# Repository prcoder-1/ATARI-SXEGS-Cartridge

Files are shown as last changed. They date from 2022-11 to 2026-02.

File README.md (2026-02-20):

# ATARI SXEGS Cartridge

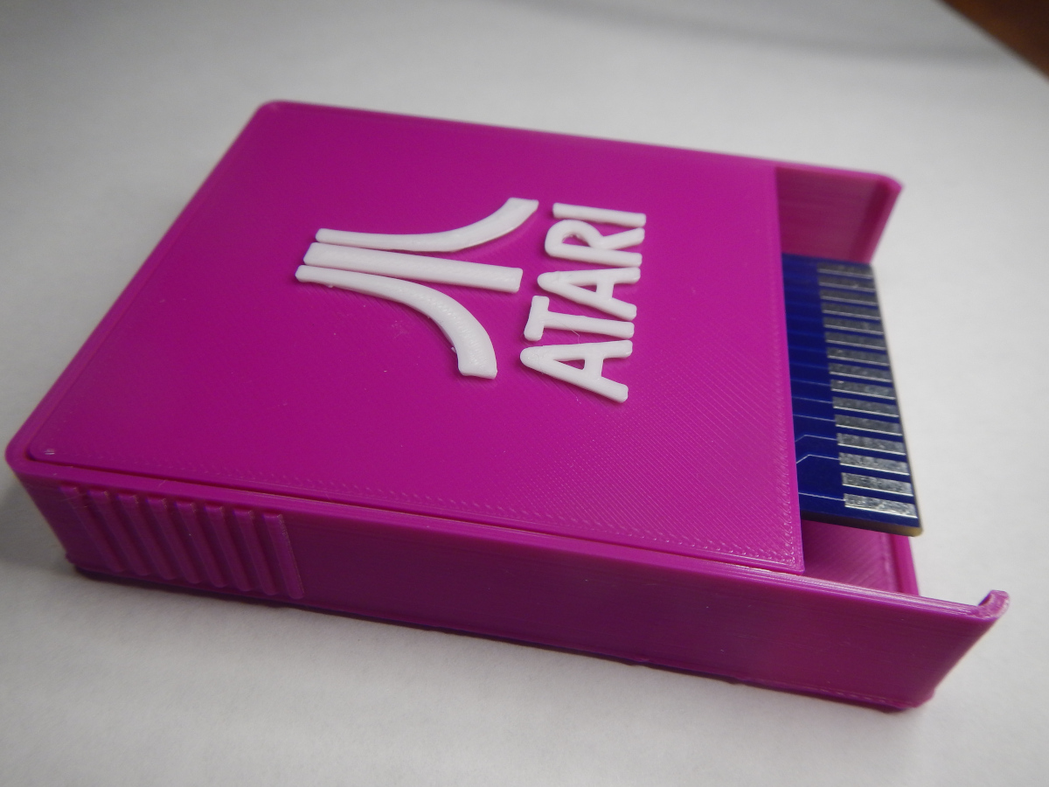
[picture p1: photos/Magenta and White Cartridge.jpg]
Magenta and White Cartridge.jpg


## Cartridge board and Housing for [ATARI 65XE/130XE/800XE/XEGS/1200XL/800XL/600XL/800/400](https://en.wikipedia.org/wiki/Atari_8-bit_family) 8-bit computers based on [SST39SF040](https://www.microchip.com/en-us/product/SST39SF040) CMOS multi-purpose **Flash memory** chip.

- This is a **[S/XEGS type cartridge](https://forums.atariage.com/topic/276194-switchable-xe-game-cartridges-swxegs-andor-sxegs/)** that allows you to store and run dozens of games.
- The project **does not use** programmable logic chips such as [GAL-chips](https://en.wikipedia.org/wiki/Generic_array_logic).
- Only conventional logic chips are used, such as **74LS00N**, **74LS74N** and **74LS374N**.
- In the process of manufacturing a cartridge, microchips of Russian production can be used, such as **ЭКР1533ИР23**, **К555ТМ2**, **К555ЛА3** etc.

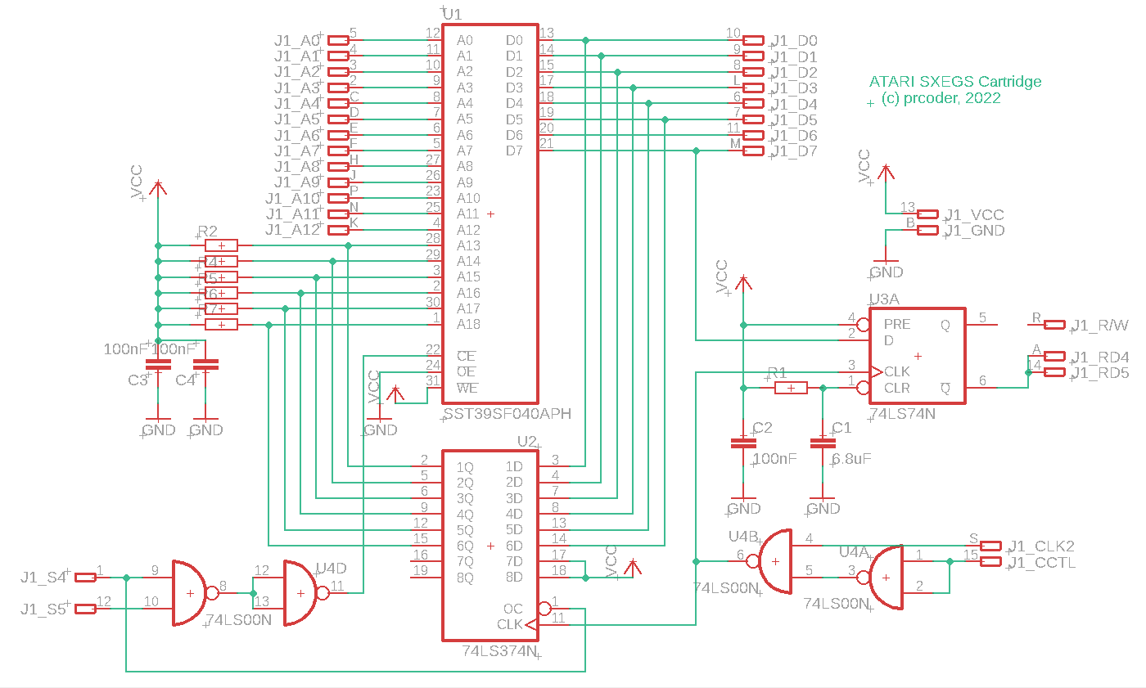
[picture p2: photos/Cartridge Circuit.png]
Cartridge Circuit


The ROM files for the cartridge are created from the XEX files using the ***[CreaXin1](programs/Creaxin1.exe)*** utility,
and then merged using the ***[XEGS Merger](programs/XEGS_merger.exe)*** to combine four files into one, forming a total of **512 kb of ROM** memory.

The cartridge body consists of two 3D-printed parts. The parts connect to each other without the use of screws or glue.

Files:
- ***[XEGS Cartridge_2022-11-28.zip](XEGS%20Cartridge_2022-11-28.zip)*** - archive with Gerber files for PCB manufacturing
- ***[ATARI-Cartridge-v5-Body.stl](ATARI-Cartridge-v5-Body.stl)*** - 3D-model of cartridge housing body
- ***[ATARI-Cartridge-v5-Cover.stl](ATARI-Cartridge-v5-Cover.stl)*** - 3D-model of cartridge housing cover

**[Ready to order project on PCBWay here](https://www.pcbway.com/project/shareproject/ATARI_8bit_SXEGS_Cartridge_Shrinked_Version_2022_11_10_3705ed31.html)**

The following DIP chips are required to build a cartridge:
- SST39SF040 DIP32 (or other JEDEC standard ROM) (1pcs)
- 74LS374N (or ЭКР1533ИР23) DIP20 (1pcs)
- 74LS74N (or К555ТМ2) DIP14 (1pcs)
- 74LS00N (or К555ЛА3) DIP14 (1pcs)

And the following SMD 1206 parts are required to build a cartridge:
- 100 nF capacitors (3 pcs)
- 6.8 uF capacitor (1 pcs)
- 11 kOhm resistors (6 pcs)
- 3.3 kOhm resistor (1 pcs)

Optional: Round Hole IC Socket Connector DIP32 (1pcs) for SST39SF040.

And you need the ability to program the [SST39SF040](https://www.microchip.com/en-us/product/SST39SF040) Flash ROM, of course. Some sort of programmer like TL866II, or something else.

To make a cartridge body, you need the ability to print models on a 3D printer. The model of the cartridge case and its cover is attached.

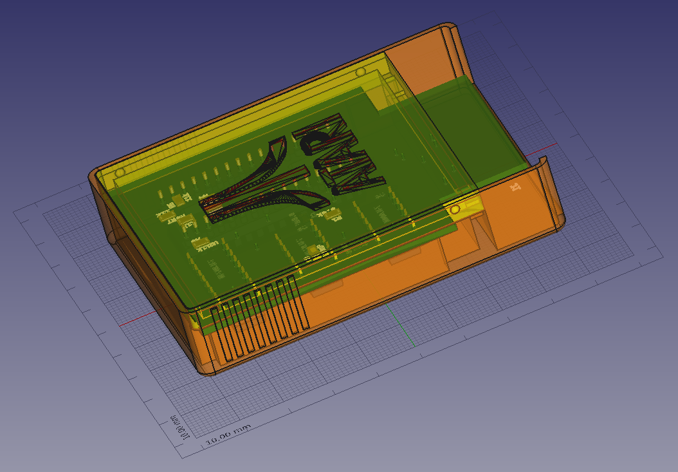
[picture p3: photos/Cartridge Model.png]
Cartridge Model


When assembling the case, no additional fasteners, screws or glue are required. The case cover simply snaps into the body of the case, securing the PCB.

Instructions for creating a binary firmware file to flash in SST39SF040:
1. Download ***[CreaXin1](programs/Creaxin1.exe)*** and ***[XEGS Merger](programs/XEGS_merger.exe)*** utilities.
2. Use '***Creaxin1.exe***' utility to create ***128 kB image file***. Add XEX files to fill 128 kB ROM space and save as 'Xin1 SXEGS cartridge ROM' file.
3. Repeat step 2 ***four times*** to create four 128 kB images with different XEXs.
4. Use '***XEGS merger.exe***' utility to merge four 128 kB images into one ***512 kB image***. Add four 128 kB ROM images, choose 512 kB FLASH SIZE and press 'Create' button.
   Enter name of the new SXEGS ROM file and save it.
5. ***Flash 512 kB ROM image*** into SST39SF040. Erase ROM chip, write image and verify it.
6. Place the written chip in round hole IC socket or solder it into PCB.

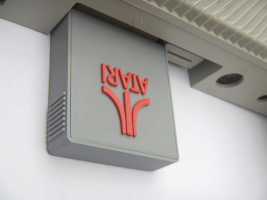
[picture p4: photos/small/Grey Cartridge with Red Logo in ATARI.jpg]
Grey Cartridge with Red Logo in ATARI

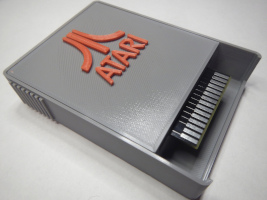
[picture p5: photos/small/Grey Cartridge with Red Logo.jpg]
Grey Cartridge with Red Logo

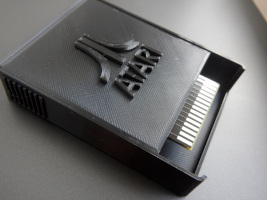
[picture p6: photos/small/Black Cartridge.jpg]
Black Cartridge

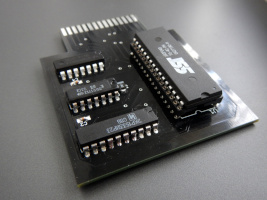
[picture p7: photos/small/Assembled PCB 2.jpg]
Assembled PCB 2

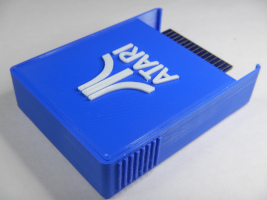
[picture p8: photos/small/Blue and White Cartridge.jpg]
Blue and White Cartridge

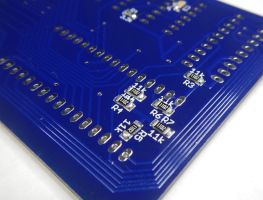
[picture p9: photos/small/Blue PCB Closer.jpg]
Blue PCB Closer

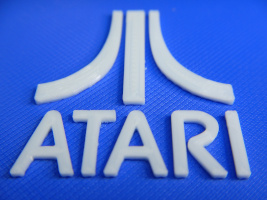
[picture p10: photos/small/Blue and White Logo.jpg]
Blue and Whte Logo

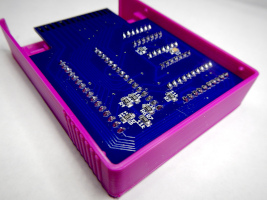
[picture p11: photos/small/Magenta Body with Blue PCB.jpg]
Magenta Body with Blue PCB

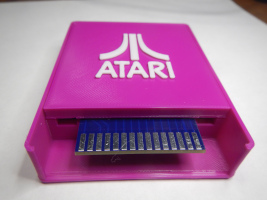
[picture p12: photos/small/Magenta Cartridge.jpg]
Magenta Cartridge

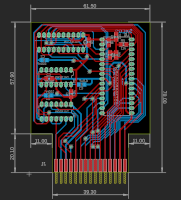
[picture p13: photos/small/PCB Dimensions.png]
PCB Dimensions

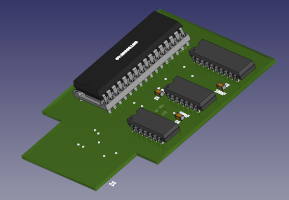
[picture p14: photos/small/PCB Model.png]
PCB Model

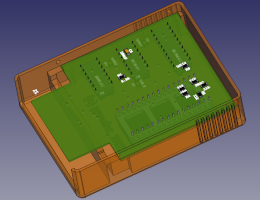
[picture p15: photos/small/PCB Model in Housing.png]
PCB Model in Housing

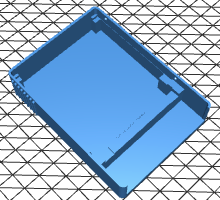
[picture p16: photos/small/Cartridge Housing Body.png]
Cartridge Housing Body

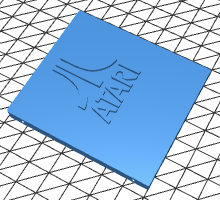
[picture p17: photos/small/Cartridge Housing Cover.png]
Cartridge Housing Cover

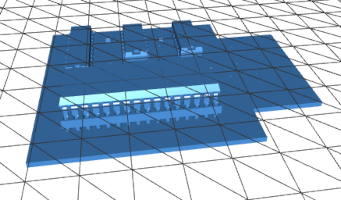
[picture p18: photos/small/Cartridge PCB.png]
Cartridge PCB

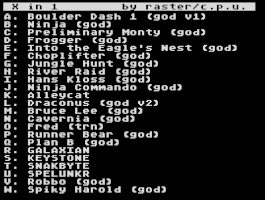
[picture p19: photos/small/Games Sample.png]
Games Sample


*© prcoder, 2022-2023*

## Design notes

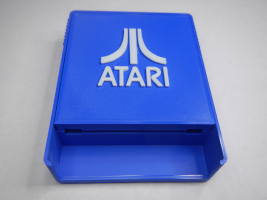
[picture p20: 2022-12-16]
photos/small/Blue Housing.jpg

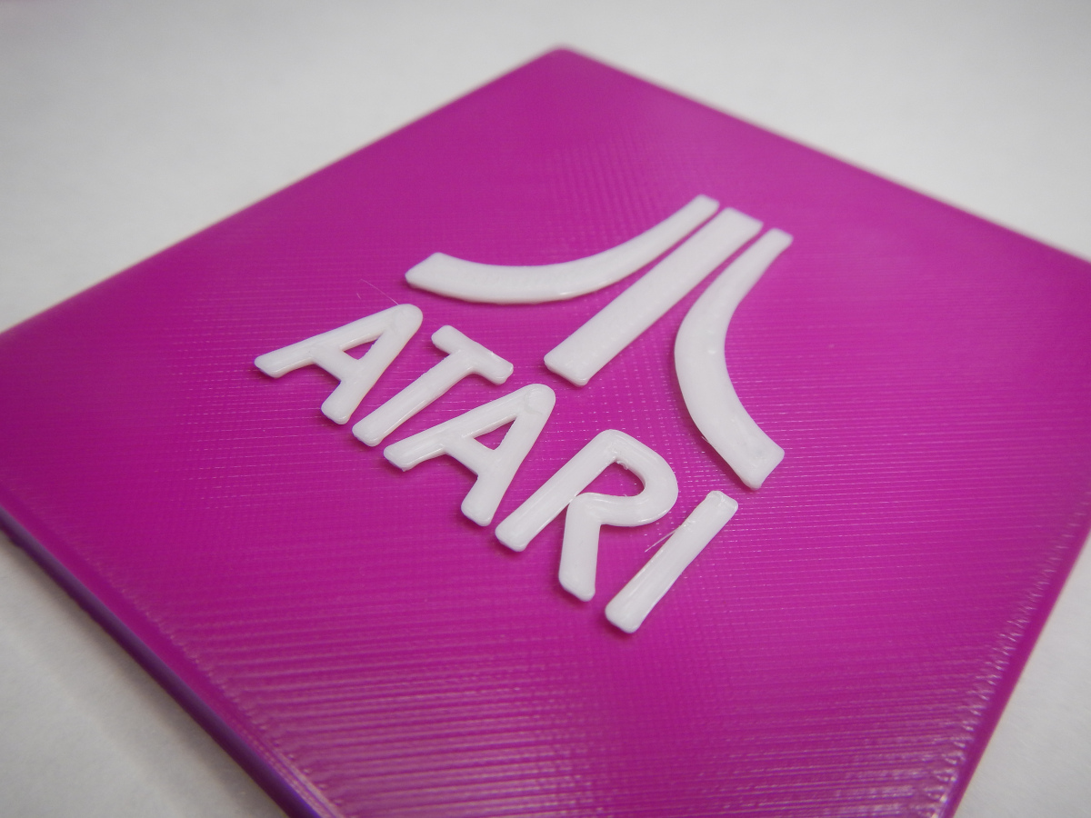
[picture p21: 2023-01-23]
photos/Magenta Cover.jpg

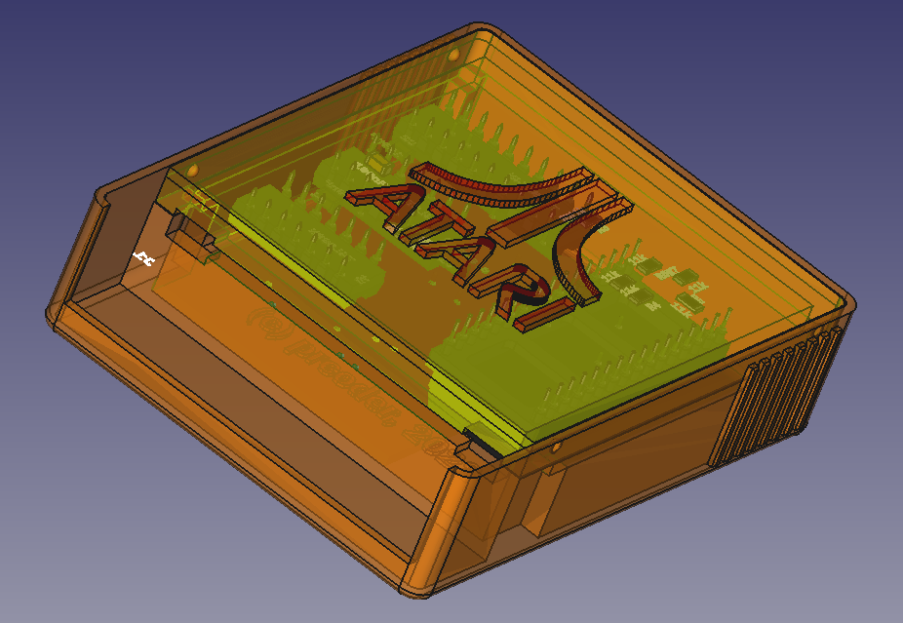
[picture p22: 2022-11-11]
photos/PCB Model with Cover closed.png

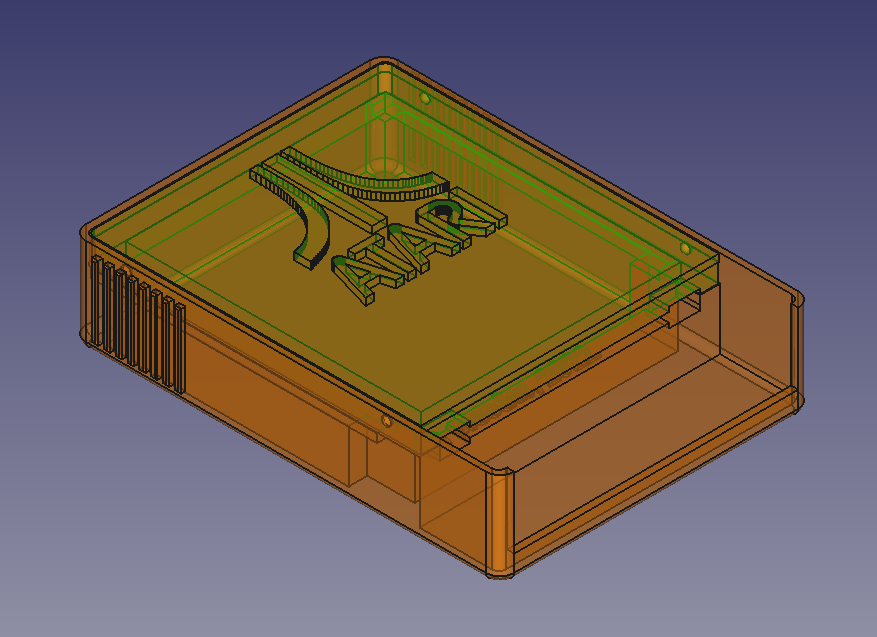
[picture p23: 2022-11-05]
photos/FreeCAD_View.png

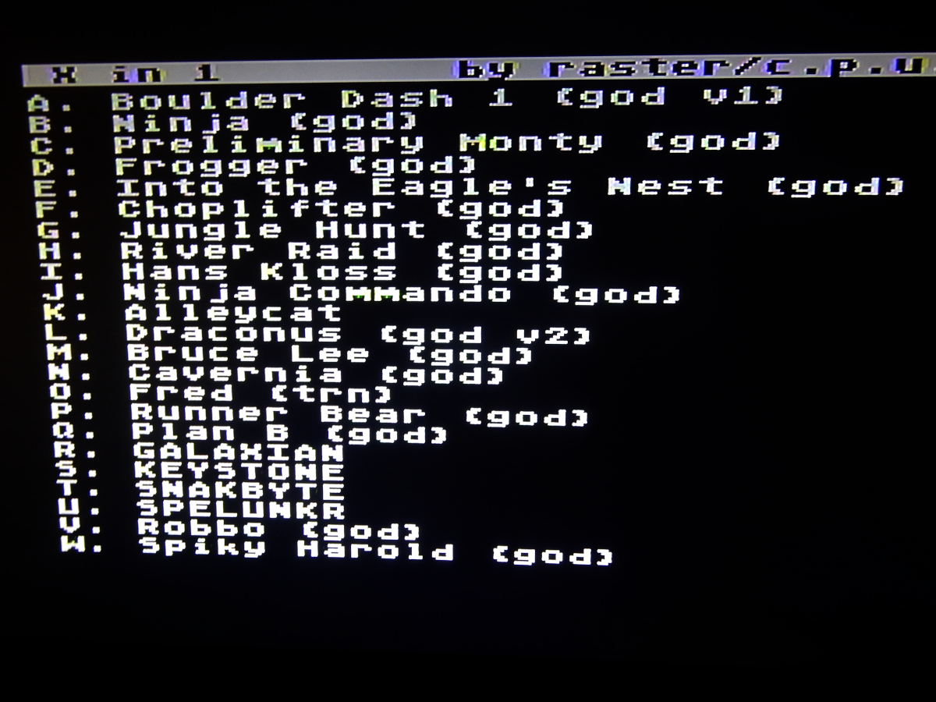
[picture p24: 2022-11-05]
photos/Games List.jpg

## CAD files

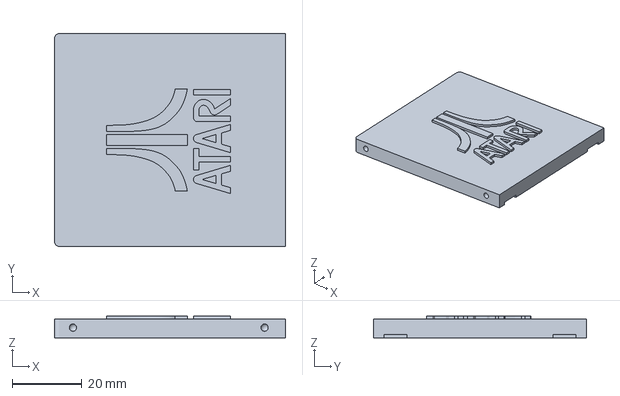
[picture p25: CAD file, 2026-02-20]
ATARI-Cartridge-v5-Cover.3mf
66.3 x 61.2 x 6.26 mm

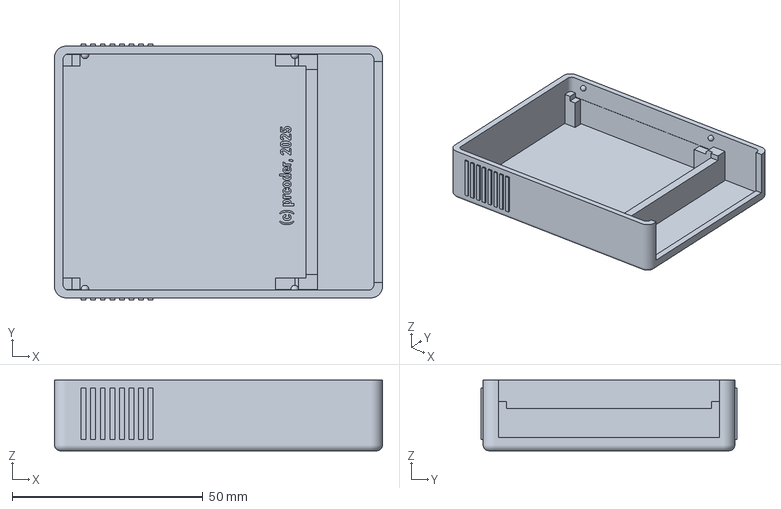
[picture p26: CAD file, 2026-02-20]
ATARI-Cartridge-v5-Body.3mf
86.0 x 67.0 x 18.5 mm

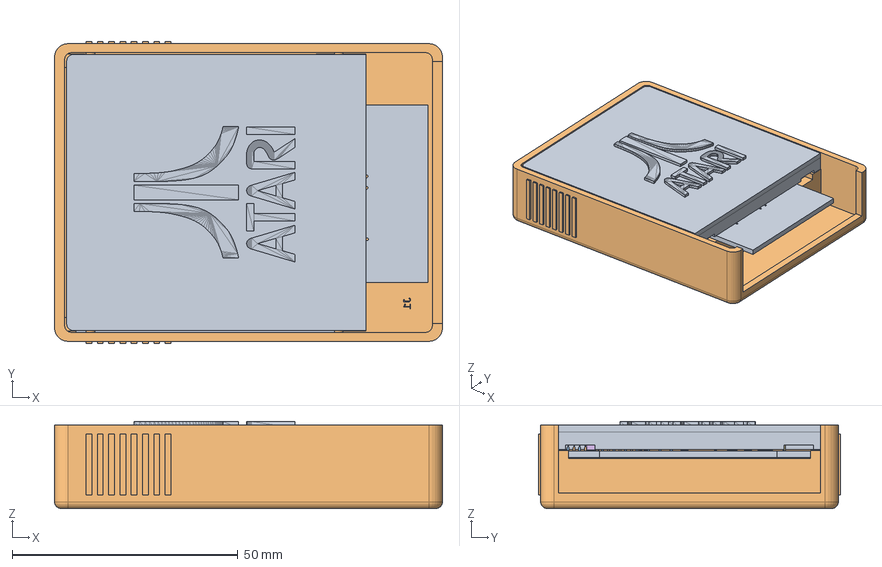
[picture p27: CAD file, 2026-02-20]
ATARI-Cartridge-v5.FCStd
86.0 x 67.0 x 19.3 mm
U3 x 2
U4 x 2
U2 x 2
R2 x 2
R3 x 2
R6 x 2
R7 x 2
R4 x 2
R5 x 2
R1 x 2
C1 x 2
C2 x 2
C4 x 2
C3 x 2
U1 Socket x 2
SST390SF40 x 2
Board x 2
PCBannotation_0000001
PCBannotation_0000
PCBannotation_0000004
PCBannotation_0000005
PCBannotation_0000006
PCBannotation_0000007
PCBannotation_0000009
PCBannotation_0000008
PCBannotation_0000011
PCBannotation_0000010
PCBannotation_0000012
PCBannotation_0000013
PCBannotation_0000014
PCBannotation_0000015
PCBannotation_0000016
PCBannotation_0000017
PCBannotation_0000018
PCBannotation_0000019
PCBannotation_0000020
PCBannotation_0000021
PCBannotation_0000023
PCBannotation_0000022
PCBannotation_0000025
PCBannotation_0000024
PCBannotation_0000026
PCBannotation_0000027
PCBannotation_0000028
PCBannotation_0000029
PCBannotation_0000030
PCBannotation_0000032
PCBannotation_0000034
Крышка с логотипом
Корпус

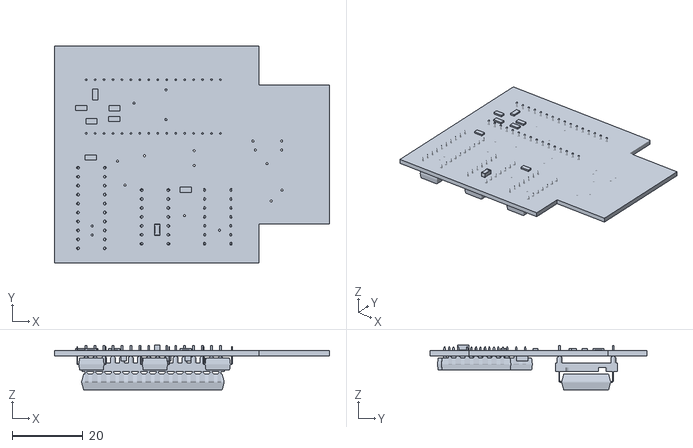
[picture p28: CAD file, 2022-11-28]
ATARI-Cartridge-v3-PCB.stl
78.0 x 61.5 x 12.8

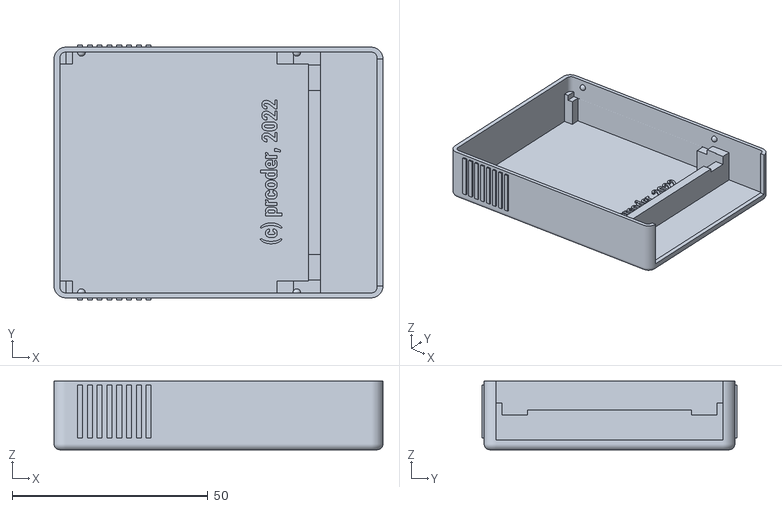
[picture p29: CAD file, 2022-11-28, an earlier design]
ATARI-Cartridge-v3-Body.stl
84.0 x 65.0 x 17.5

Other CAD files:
ATARI-Cartridge-v3-Cover.stl
ATARI-Cartridge-v5-Body.stl
ATARI-Cartridge-v5-Cover.stl

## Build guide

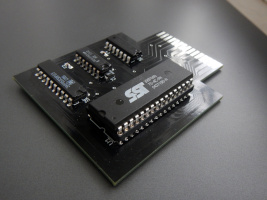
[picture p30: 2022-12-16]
photos/small/Assembled PCB 1.jpg

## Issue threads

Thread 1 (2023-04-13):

74HC instead 74LS?

titos-carrasco, 2023-04-13:
May i use 74HC series instead 74LS? I'm getting a green screen

prcoder-1, 2023-04-13:
In fact, I have not tried it and I myself do not know if it will work with HC series.
The 74LS is Transistor to Transistor logic. The 74HC uses MOSFET technology and it can operate with wider variety of voltages. Transition speeds are not too much different.
I think the green screen is not related to this. What model of computer do you have and how do you insert the cartridge?
For ATARI 65XE, the cartridge must be inserted with the parts down to the table so that the chips are not visible when the board is inserted into the computer.
Several of my cartridges also gave out a green screen due to the fact that the SMD components were poorly soldered and flux remained somewhere under them. Reheating with a hot air helped in all cases.

titos-carrasco, 2023-04-14:
Ok, now is working with 74hc chips, but with garbage in  a 65xe with 130xe motherboard and 128kb ram.

No problem in 800xl

prcoder-1, 2023-04-14:
I have ten cartridges working without problems on my 65XE with a 512Kb memory extension (by TFHH).

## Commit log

2022-11-05 Initial commit of ATARI SXEGS Cartridge Gerber files and STL files.
    [ATARI-Cartridge-v2-Body.stl, ATARI-Cartridge-v2-Cover.stl]
2022-11-05 Adding thumbnails for STL-Models.
2022-11-07 Photo of grey cartridge housing added.
2022-11-08 Small changes in README.md file.
    [ATARI-Cartridge-v2-Body.stl]
2022-11-09 Cartridge dimensions reduced to 64mm wide for compatibility with 1200XL/800XL/400 models.
    [ATARI-Cartridge-v2-Body.stl, ATARI-Cartridge-v2-Cover.stl, ATARI-Cartridge-v3-Body.stl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]
2022-11-09 Old Gerber files removed.
2022-11-10 Cartridge dimensions reduced to 84x64x20 mm.
    [ATARI-Cartridge-v3-Body.stl, ATARI-Cartridge-v3-Cover.stl]
2022-11-27 The length of the seat for the PCB has been increased to 58.2 mm.
    [ATARI-Cartridge-v3-Body.stl, ATARI-Cartridge-v3-Cover.stl]
2022-11-28 Added schematic and PCB model.
    [ATARI-Cartridge-v3-Body.stl, ATARI-Cartridge-v3-Cover.stl, ATARI-Cartridge-v3-PCB.stl]
2022-11-28 Added photos of the blue housing of the cartridge.
2022-11-28 Updated Gerber files.
2022-12-16 New photos of blue PCB and housing added.
2026-02-20 Version 5 of cartridge case added.
    [ATARI-Cartridge-v5-Body.3mf, ATARI-Cartridge-v5-Body.stl, ATARI-Cartridge-v5-Cover.3mf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]
2026-04-08 Link to PCBWay project changed.
